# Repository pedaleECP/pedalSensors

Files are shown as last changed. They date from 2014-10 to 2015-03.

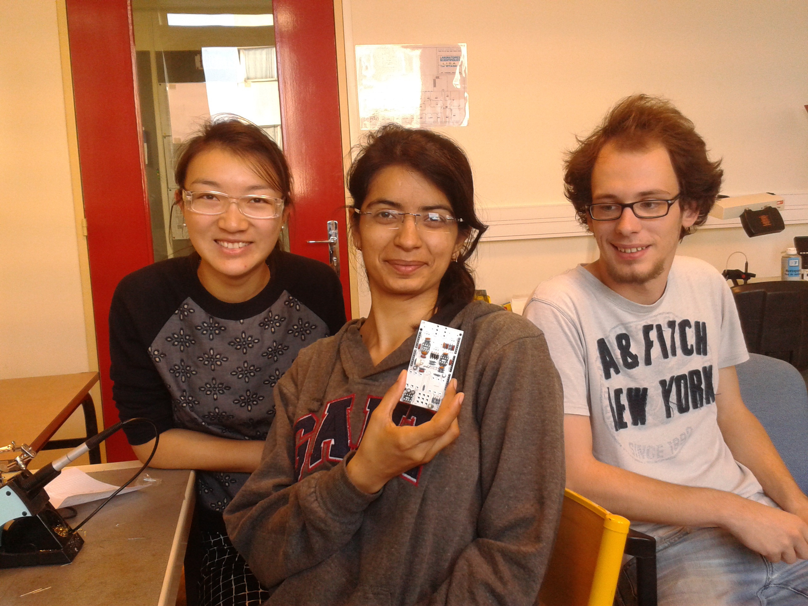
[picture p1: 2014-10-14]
Documentation/Photos/2014-09-30 Scéance 2 - Fabrication du pedalSHIELD/IMG_20140930_173658.jpg

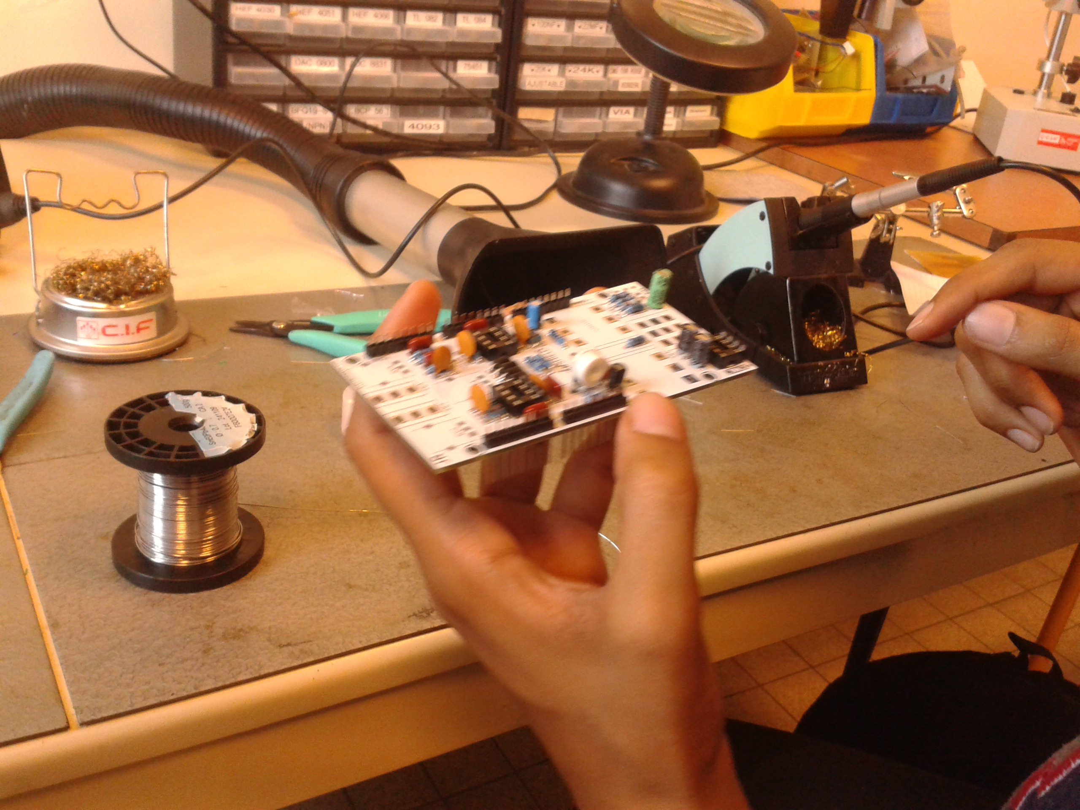
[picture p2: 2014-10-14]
Documentation/Photos/2014-09-30 Scéance 2 - Fabrication du pedalSHIELD/IMG_20140930_173621.jpg

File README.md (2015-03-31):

pedalSHIELD
===========

Check from Esteban
Deuxieme chek from Esteban

pedalSHIELD is an Arduino Open Source guitar pedal made for guitarists, hackers and programmers. Users can program their own effects in C/C++ or download ready effects from the online library.

It is designed to be a platform to learn about digital signal processing, effects, synthesizers and experiment without deep knowledge in electronics or programming

All info in www.electrosmash.com/pedalshield

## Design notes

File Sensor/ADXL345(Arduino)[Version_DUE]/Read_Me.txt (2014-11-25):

The code is provided under the MIT license please use, edit, change, and share. 

The Adxl345 library has been modified for use with this example
The Adxl345 library however is provided under the GPL V2 license.

Before loading the ADXLl345_example code, or even opening the arduino software, place the Adxl345 folder in your arduino library.

////ARDUINO LIBRARY LOCATION////
On your Mac:: In (home directory)/Documents/Arduino/libraries
On your PC:: My Documents -> Arduino -> libraries
On your Linux box: (home directory)/sketchbook/libraries

##Changes from pedalSensors team:
We adapted the library to be used with ArduinoDUE

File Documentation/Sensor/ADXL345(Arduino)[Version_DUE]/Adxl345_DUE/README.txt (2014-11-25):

Adaptadted version of the ADXL345 library for Arduino DUE from pesalSensors team

based in "masc" post in http://forum.bildr.org/viewtopic.php?f=29&t=349&start=75

Arduino Due should be connected as follows:

ADXL345					Arduino DUE
3.3V	-----------------------------	3.3V
GND	-----------------------------	GND
SCL	-----------------------------	SCL 21
SDA	-----------------------------	SDA 20

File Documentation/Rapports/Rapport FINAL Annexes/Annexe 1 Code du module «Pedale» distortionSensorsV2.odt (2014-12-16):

Annexe 1

Code du module «Pedale»

distortionSensorsV2.ino

/*********************************************************************

*********** distortion Effect for the MovingTones pedal **********

*********** made by the MovingTones team **********

*********** website :) **********

* Licensed under a Creative Commons Attribution 3.0 Unported License *

**********************************************************************

*********** effect adapted from the distortion effect by ***********

*********** www.electrosmash.com/pedalshield **********

*********** Based on rcarduino.blogspot.com previous work **********

**********************************************************************/

/* To make this code compile you will need the following libraries:

* Adafruit_ST7735

* Adafruit_GFX

* SPI.h

* EEPROM.h */

// Libraries

#include "EEPROM.h" //

#include <Adafruit_GFX.h> // Core graphics library

#include <Adafruit_ST7735.h> // Hardware-specific library

#include <SPI.h> // Used during debugging to show messages on the Serial print

// Variables from the original effects' code

int in_ADC0, in_ADC1; // variables for 2 ADCs values (ADC0, ADC1)

int POT0, POT1, POT2, out_DAC0, out_DAC1; // variables for 3 pots (ADC8, ADC9, ADC10)

const int LED = 3; // LED in pin 3

const int FOOTSWITCH = 7; // Footswitch in pin 7

const int TOGGLE = 2; // Toggle in pin 2

int upper_threshold, lower_threshold; // Variable for the distortion effect

const int SAVE_BUTTON = 1; // pins of the arduino

const int TFT_CS = 10;

const int TFT_RST = 8;

const int TFT_DC = 9;

Adafruit_ST7735 tft = Adafruit_ST7735(TFT_CS, TFT_DC, TFT_RST); // instantiate the screen

// New variables

const int STANDBY1_MODE = 0; // effects will only be applied when the pedal's footswitch is on HIGH

const int BUTTON_MODE = 1; // sequence of pressing produces: low-high-low-high or high-low-high-low

const int STANDBY2_MODE = 2; // if initially footswitch is HIGH, we will go to BUTTON_MODE

const int SENSOR_MODE = 3; // if intiially footswitch is LOW, we will go to STANDBY1_MODE

const int DEBOUNCE_DELAY = 50; // delay to be applied to debounce

const int MIN = 0; // range of the parameters p0, p1, p2 for the effects' code

const int MAX = 4096;

const int MIN_SCREEN = 0; // length of the bar graph to be displayed on the screen

const int MAX_SCREEN = 115;

const int MAX_POT = 4096; // readings from the bottons will be scaled to this range

const int MIN_POT = 0;

const int LIMIT_POT = 4096;

const int MAX_SENSORS = 180; // sensors send angles in this range throught the XBees

const int MIN_SENSORS = 0;

int footswitch_detect; // variables to fascilitate the toggle

int footswitch_detect_last;

int footswitch_detect_previous;

int save_button_detect; // currently not used

int save_button_press_time;

boolean save_button_pressed;

int footswitch_mode = STANDBY1_MODE; // instantiate footswitch_mode to STANDBY1_MODE

int last_debounce_time = 0; // variables to fascilitate debouncing

int last_update_time = 0;

int p0 = 0, p1 = 0, p2 = 0; // parameters to be used by the code to apply effects accordingly

int p0_old, p1_old, p2_old;

int MEMORYPOTMOD0 = 0, MEMORYPOTMOD1 = 0, MEMORYPOTMOD2 = 0;

// Variables needed for the comunication with the ArduinoNano who is sending information in Serial Port

byte incomingByte; //Bytes that are going to be used to add them and to see if there is any header between they two.

byte lastByte; // This will be just the byte before incomingByte

// Variables to assemble 16-bits ints from bytes received form the Arduino Nano through the XBees

// !!! Note that int on an Arduino DUE is 32-bit but in many other smaller Arduinos it is 16-bit

// Thus to avoid negative-wrapping-around-to-positive, use int16_t for all int variables in this program

int16_t currentInt;

int16_t int1;

byte byteArray[3];

int16_t angles[3]; // the three angles read by the sensor as received from XBees

int16_t mask;

void setup()

{

//Configuration from the original effect from pedalShield

//ADC Configuration

ADC->ADC_MR |= 0x80; // DAC in free running mode.

ADC->ADC_CR = 2; // Starts ADC conversion.

ADC->ADC_CHER = 0xFFFF; // Enable all ADC channels

//DAC Configuration

analogWrite(DAC0, 0); // Enables DAC0

analogWrite(DAC1, 0); // Enables DAC1

// We are going to read from the FootSwitch to make our 3 modes.

pinMode(FOOTSWITCH, INPUT); // Enables to read from the footswitch

// pinMode(SAVE_BUTTON, INPUT);

pinMode(LED, OUTPUT);

// record the state of the footswitch when turned on

/*HERE WE SHOULD DETECT IF HI IS ALEREADY IN BYPASSMODE OR NOT. AND THEN START FROM HIS ORIGINAL STATE

*******************************************************************************************************/

footswitch_mode = digitalRead(FOOTSWITCH);

footswitch_detect_last = digitalRead(FOOTSWITCH);

footswitch_detect_previous = footswitch_detect_last;

//Screen (add description and comments)

tft.initR(INITR_BLACKTAB);

tft.fillScreen(ST7735_BLACK);

// Here we set the screen parameters: orientation, text size, color and text display

tft.setRotation(-1);

tft.setTextSize(2);

tft.fillScreen(ST7735_WHITE);

tft.setTextColor(ST7735_RED);

tft.println("*Distortion*");

tft.println("");

tft.println(" P1");

tft.println("");

tft.println(" P2");

tft.println("");

tft.println(" P3");

p0_old = p0;

p1_old = p1;

p2_old = p2;

// Initialize the Serial ports for message transmissions

Serial.begin(57600); //Initialize the port for comunication with the PC to send messages useful for coding (Serial)

Serial1.begin(57600); //Initialize the port for comunication with the XBee (Serial1)

// From XBee

lastByte = (byte)0; // We inicialize the lastBythe with 0 so it can make its first comparison.

}

void loop()

{

readFootSwitch(); //We read the FootWwitch State and we see if it's pressed.

updateScreen(); //We upload the screen information

// readSaveButton();

// From the original effect code

// Read the ADCs

while ((ADC->ADC_ISR & 0x1CC0) != 0x1CC0); // wait for ADC 0, 1, 8, 9, 10 conversion complete.

in_ADC0 = ADC->ADC_CDR[7]; // read data from ADC0

in_ADC1 = ADC->ADC_CDR[6]; // read data from ADC1

// POT0=ADC->ADC_CDR[10]; // read data from ADC8

// POT1=ADC->ADC_CDR[11]; // read data from ADC9

// POT2=ADC->ADC_CDR[12]; // read data from ADC10

// Changing the parameters values depending of the mode

switch (footswitch_mode) {

case STANDBY1_MODE:

case STANDBY2_MODE:

Serial.print("Standby Mode ");

break;

case BUTTON_MODE:

Serial.print("Button Mode: ");

readPotentiometer();

break;

case SENSOR_MODE:

Serial.print("Sensor Mode: ");

readSensor();

break;

default:

Serial.print("Invalid state ");

}

// We display the parameters values on the computer screen

Serial.print(p0);

Serial.print("|");

Serial.print(p1);

Serial.print("|");

Serial.print(p2);

Serial.print("|");

Serial.println("");

// Code for the effect 'distortion' - distortion does not use parameter p1

// Code from the original effect: This is the effect, taking the parameters p0, p1 and p2

upper_threshold = map(p0, 0, 4095, 4095, 2047);

lower_threshold = map(p0, 0, 4095, 0000, 2047);

if (in_ADC0 >= upper_threshold) in_ADC0 = upper_threshold;

else if (in_ADC0 < lower_threshold) in_ADC0 = lower_threshold;

if (in_ADC1 >= upper_threshold) in_ADC1 = upper_threshold;

else if (in_ADC1 < lower_threshold) in_ADC1 = lower_threshold;

//adjust the volume with POT2

out_DAC0 = map(in_ADC0, 0, 4095, 1, p2);

out_DAC1 = map(in_ADC1, 0, 4095, 1, p2);

//Write the DACs

dacc_set_channel_selection(DACC_INTERFACE, 0); //select DAC channel 0

dacc_write_conversion_data(DACC_INTERFACE, out_DAC0); //write on DAC

dacc_set_channel_selection(DACC_INTERFACE, 1); //select DAC channel 1

dacc_write_conversion_data(DACC_INTERFACE, out_DAC1); //write on DAC

}

// reading the FOOTSWITCH on the pedalShield and implement a debouncing mechanism

void readFootSwitch() {

footswitch_detect = digitalRead(FOOTSWITCH);

if (footswitch_detect != footswitch_detect_last) {

last_debounce_time = millis();

}

if (footswitch_detect != footswitch_detect_previous && millis() - last_debounce_time > DEBOUNCE_DELAY) {

footswitch_mode = (footswitch_mode + 1) % 4;

footswitch_detect_previous = footswitch_detect;

}

footswitch_detect_last = footswitch_detect; // we detect changes in the FOOTSWITCH by comparing these two variables

}

void readSaveButton() {

save_button_detect = digitalRead(SAVE_BUTTON);

if (save_button_detect == HIGH) {

last_debounce_time = millis();

if (save_button_pressed = true) {

if (millis() - save_button_press_time > 3000) {

EEPROM.write(0, p0);

EEPROM.write(1, p1);

EEPROM.write(2, p2);

} else {

p0 = EEPROM.read(0);

p1 = EEPROM.read(1);

p2 = EEPROM.read(2);

}

save_button_pressed = false;

}

}

if (save_button_detect == LOW && millis() - last_debounce_time > DEBOUNCE_DELAY && save_button_pressed == false) {

save_button_press_time = millis();

save_button_pressed = true;

}

}

void readPotentiometer() {

int POTMOD0 = ADC->ADC_CDR[2]; //reading first potentiometer

POT0 = updatePot(POT0, MEMORYPOTMOD0, POTMOD0); //update first parameter using current reading of potentiometer

p0 = POT0; //update globally

MEMORYPOTMOD0 = POTMOD0; //now the potentiometer reading becomes the 'previous' reading

//Serial.println(p0);

int POTMOD1 = ADC->ADC_CDR[1]; //read from pot1 //reading second potentiometer

POT1 = updatePot(POT1, MEMORYPOTMOD1, POTMOD1); //update second parameter using current reading of potentiometer

p1 = POT1; //update globally

MEMORYPOTMOD1 = POTMOD1; //now the potentiometer reading becomes the 'previous' reading

int POTMOD2 = ADC->ADC_CDR[0]; //read from pot2 //reading third potentiometer

POT2 = updatePot(POT2, MEMORYPOTMOD2, POTMOD2); //update third parameter using current reading of potentiometer

p2 = POT2; //update globally

MEMORYPOTMOD2 = POTMOD2; //now the potentiometer reading becomes the 'previous' reading

}

int updatePot(int POT, int MEMORYPOTMOD, int POTMOD) { //update the given parameter

int VALUE = 0; //Value to be added to previous values of parameters

if ((POTMOD - MEMORYPOTMOD) < -0.9 * MAX_POT) { // case of more than one complete turn in the positive direction

VALUE = MAX_POT + POTMOD - MEMORYPOTMOD;

if ((POT + VALUE) > LIMIT_POT) {

POT = LIMIT_POT;

}

else {

POT = POT + VALUE ;

}

}

else if ((POTMOD - MEMORYPOTMOD) > 0.9 * MAX_POT) { // case of more than one complete turn in the negative direction

VALUE = - (MAX_POT) + POTMOD - MEMORYPOTMOD;

if ((POT + VALUE) < MIN_POT) {

POT = MIN_POT;

}

else {

POT = POT + VALUE ;

}

}

else if ((POTMOD - MEMORYPOTMOD) > 0) { //case of less than one complete turn in the positive direction

VALUE = POTMOD - MEMORYPOTMOD;

if ((POT + VALUE) > LIMIT_POT) {

POT = LIMIT_POT;

}

else {

POT = POT + VALUE ;

}

}

else if ((POTMOD - MEMORYPOTMOD) < 0) { //case of less than one complete turn in the negative direction

VALUE = POTMOD - MEMORYPOTMOD;//+POTSENSOR

if ((POT + VALUE) < MIN_POT) {

POT = MIN_POT;

}

else {

POT = POT + VALUE ;

}

}

return POT;

}

// Read the 3 angles transmitted by the XBees if there is message available

// The 3 angles (6 bytes) are always sent together following an int header == -21846

void readSensor() {

if (Serial1.available()) {

boolean header = false; // before a valid header is detected, header is set to false

lastByte = Serial1.read(); // read one byte

while (Serial1.available() && !header) {

incomingByte = Serial1.read(); // read another byte

int1 = assembleInt(lastByte, incomingByte); // each int is 16-bit, so we assemble the incoming int by applying bit-wise operations on the two bytes

// Serial.println("waiting"); // uncomment this line to see how long it takes to clear the buffer

if (int1 == -21846) {

header = true; // a correct header is detected

}

else {

lastByte = incomingByte; // if there is not any header we take our second byte as our first byte, to then make a comparison with the following

}

}

// if the header is detected, the next 6 bytes are the 3 values of the angles (each int is 16-bit)

readAngles();

}

}

// assemble an int from the two bytes just read into byteArray

int16_t assembleInt(byte byte1, byte byte2) {

currentInt = (int16_t)byte1 << 8;

mask = 0xFF;

mask = mask & (int16_t)byte2; // mask the first 8 bit to zero, in case the byte is sign-extended

currentInt = currentInt | mask;

// the byte1*256 + byte2 before is wrong because byte2 had been sign-extended - have to mask the first 8 bits

//mask = 0xFF;

//currentInt = byte1*256 + (byte2 & mask);

return currentInt;

}

// Read the angles from the next 6 bytes (2 bytes for each 16-bit int angle)

void readAngles() {

// Expect 3 angles

for (int i = 0; i < 3; i++) {

/* We know that we should have a message in the buffer, (because we have reconized an header)

but, it can happen that the pedal tries to read the angles form the Serial before the sensor

manage to send him the angles (it can also be because of the data transmission speed v/s

the pedal's processor speed)

so here we wait for the next message if it's necessary

TODO: Use a timout!!*/

while (!Serial1.available()) {

Serial.println("----Im waiting111111-");

}

byteArray[0] = Serial1.read(); // We read the fist byte

while (!Serial1.available()) { // We wait again in case it is necesary TODO: Use a timout!!

Serial.println("----Im waiting222222-");

}

byteArray[1] = Serial1.read(); // We read the second byte

angles[i] = assembleInt(byteArray[0], byteArray[1]); // We construct the angle using both bytes

}

/*Sometimes, (and I don't know yet why.. and this is a ToDo:try to prevent this from another way)

there are some messages that are eathier read badly or sended badly.. so we delete any message with an

incorrect angle*/

if (angles[0] >= 0 && angles[0] <= MAX_SENSORS && angles[1] >= 0 && angles[1] <= MAX_SENSORS && angles[2] >= 0 && angles[2] <= MAX_SENSORS) {

// Writing the angles into the global variables

p0 = angles[0] * 4096 / MAX_SENSORS; //Here we scale the angle into our effect scale. here is until 4096

p1 = angles[1] * 4096 / MAX_SENSORS;

p2 = angles[2] * 4096 / MAX_SENSORS;

}

}

void updateScreen() {

// only update the screen every 0.1 seconds

if (millis() - last_update_time > 100) {

last_update_time = millis();

// if the new parameter is bigger than the old one, add a blue bar

// else add a white bar. this scheme is applied for every parameter.

if (p0_old < p0) {

tft.fillRoundRect(MIN_SCREEN, 32, map(p0, MIN, MAX, MIN_SCREEN, MAX_SCREEN), 16, 0, ST7735_BLUE);

}

if (p0_old > p0) {

tft.fillRoundRect(map(p0, MIN, MAX, MIN_SCREEN, MAX_SCREEN), 32, map(p0, MIN, MAX, MAX_SCREEN, MIN_SCREEN), 16, 0, ST7735_WHITE);

}

p0_old = p0;

if (p1_old < p1) {

tft.fillRoundRect(MIN_SCREEN, 64, map(p1, MIN, MAX, MIN_SCREEN, MAX_SCREEN), 16, 0, ST7735_BLUE);

}

if (p1_old > p1) {

tft.fillRoundRect(map(p1, MIN, MAX, MIN_SCREEN, MAX_SCREEN), 64, map(p1, MIN, MAX, MAX_SCREEN, MIN_SCREEN), 16, 0, ST7735_WHITE);

}

p1_old = p1;

if (p2_old < p2) {

tft.fillRoundRect(MIN_SCREEN, 96, map(p2, MIN, MAX, MIN_SCREEN, MAX_SCREEN), 16, 0, ST7735_BLUE);

}

if (p2_old > p2) {

tft.fillRoundRect(map(p2, MIN, MAX, MIN_SCREEN, MAX_SCREEN), 96, map(p2, MIN, MAX, MAX_SCREEN, MIN_SCREEN), 16, 0, ST7735_WHITE);

}

p2_old = p2;

}

}

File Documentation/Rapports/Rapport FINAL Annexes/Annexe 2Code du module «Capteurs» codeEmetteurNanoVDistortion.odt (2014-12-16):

Annexe 2

Code du module «Capteurs»

codeEmetteurNanoVDistortion.ino

/*********************************************************************

*********** code pour l'emeteur des angles Yaw,Roll,Pitcc **********

*********** made by the MovingTones team **********

*********** website :) **********

* Licensed under a Creative Commons Attribution 3.0 Unported License *

**********************************************************************/

/* Les angles ici envoyes seront les angles Yaw,Roll,Pich

plus d'info : http://en.wikipedia.org/wiki/Aircraft_principal_axes

C'est necesaire d'avoir les libreries suivantes:

* FreeSixIMU

* FIMU_ADXL345

* FIMU_ITG3200

Vous pouvez les trouver sur:

http://bildr.org/2012/03/stable-orientation-digital-imu-6dof-arduino/*/

//Importation des bilbiotheques

#include <FreeSixIMU.h>

#include <FIMU_ADXL345.h>

#include <FIMU_ITG3200.h>

#include <Wire.h>

float angles[3]; //Ici on va stocker les angles.

//float accel[3]; //Si jamais on a besoin des accelerations

FreeSixIMU sixDOF = FreeSixIMU(); // Set the FreeSixIMU object

void setup() {

Wire.begin();

Serial.begin(57600); //C'est necesaire pour envoyer les messages via XBee

delay(5);

sixDOF.init(); //begin the IMU

delay(5);

}

void loop() {

//sixDOF.getEuler(angles); //Si jamais on a besoin des angles d'euler

//sixDOF.getValues(accel); //Si jamais on a besoin des accelerations

sixDOF.getYawPitchRoll(angles); //On a choisi d'utiliser ces angles car sont plus intuitives dans le mouvement

angles[0]=abs(angles[0]); // Comme l'angle va de -180 a +180 on le change pour etre de 0 --- 150--180--150--0 etc...

//Mais en fait l'angle Yaw va de -180 jusqu'a +180, donc on va se restrindre a la plage 0 180.

//TODO: Take advantaje of this large angle.

// if (angles[0]>180){angles[0]=180;}

// if (angles[0]<0){angles[0]=0;}

angles[1]=angles[1]+90; // Comme l'angle va de -90 a +90 on le change pour etre de 0 a 180

angles[2]=angles[2]+90; // Comme l'angle va de -90 a +90 on le change pour etre de 0 a 180

//Si on a besoin de voir les angles qu'on envoie, on peut les afficher sur l'ecran de l'ordinateur

//Mais il y aura des problemes dans les messages recoit par la pedale: L'ordinateur et le Xbee utilisent le meme port serial de l'arduino nano (unique)

/* Serial.print(angles[0]);

Serial.print(" | ");

Serial.print(angles[1]);

Serial.print(" | ");

Serial.print(angles[2]);

Serial.println();*/

envoyeAngles(angles[1],angles[0],angles[2]); //On envoie finnalement les angles a la pedale a travers du port Serial.

}

void envoyeAngles(float psi, float theta, float phi){

int16_t psiInt = (int16_t)(psi); //On va envoyer des integers, car c'est plus facile et on n'a pas besoin d'assez de precition

int16_t thetaInt = (int16_t)(theta); //On va envoyer des integers, car c'est plus facile et on n'a pas besoin d'assez de precition

int16_t phiInt = (int16_t)(phi); //On va envoyer des integers, car c'est plus facile et on n'a pas besoin d'assez de precition

//Ici, pour chaque angle en variable type integer, on va lui diviser en deux octets en on va lui envoyer un par un

//Toud d'abord on envoye le "header" qui est 0xAAAA= -21846

Serial.write(0xAAAA/ 256); //on envoye la premiere partie

Serial.write(0xAAAA% 256); //on envoye la deuxieme partie

Serial.write(psiInt / 256); //on envoye la premiere partie

Serial.write(psiInt% 256); //on envoye la deuxieme partie

Serial.write(thetaInt / 256); //on envoye la premiere partie

Serial.write(thetaInt% 256);

Serial.write(phiInt/ 256); //on envoye la premiere partie

Serial.write(phiInt% 256); //on envoye la deuxieme partie

}

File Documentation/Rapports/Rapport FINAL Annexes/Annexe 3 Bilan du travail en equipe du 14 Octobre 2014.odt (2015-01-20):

Annexe 3 - Bilan du travail en équipe du 14 Octobre 2014

Notre stratégie a été de se répartir en petits groupes(deux ou trois) en fonction des tâches à venir. Cela permet une organisation libre et permet de ne pas se restreindre à un type de tâche spécifique (hardware/software, par exemple). Nous avons trouvé cette stratégie efficace: programmation, assemblage des composants, soudure et recherche sur Internet sont plus efficaces en petits groupes, qui permettent d’avoir assez de place pour s’exprimer, sans avoir à faire trop de coordination ce qui résulte en un travail à la fois rapide et efficace.

Cependant, il est important d’avoir des réunions ensemble, nous avons donc des réunions tous ensemble chaque mardi, comme ça nous pouvons rester informés des progrès de notre projet entier, et nous pouvons aussi discuter, attribuer les tâches à venir et demander de l’aide si un petit groupe ne peut pas résoudre un problème dans le planning. En même temps, nous voulons maintenir une atmosphère détendue et pas stressante.

Nous sommes très heureux d’avoir un groupe extraordinairement divers: chacun de nous a une nationalité différente (Chine, Inde, Mexique, Allemagne, France et Chili). Le plupart d’entre nous sont étudiants en échange ce qui permet de partager les techniques et des plate-formes que nous utilisions dans nos universités (cf Asana, GitHub, dynamiques de travail en équipe). Après ce semestre, nous les remporterons chez nous et les utiliserons dans nos futurs projets. Il y a donc un enrichissement personnel et culturel.

En outre, l’idée d’un projet Open Source nous enthousiasme, ainsi que le fait de contribuer à la communauté en ligne et d’exposer l’idée aux étudiants à l’Ecole Centrale Paris.

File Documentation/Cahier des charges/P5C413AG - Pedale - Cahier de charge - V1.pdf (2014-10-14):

P5C413AG - 2014 - Cahier des charges

Cahier des charges.

Nom du Projet: Pédale d'effet numérique pour guitare électrique

Code du Projet: P5C413AG

Encadrant du Projet: Jean-Pierre FANTON

Membres du groupe:

- AHUJA, Sanju
- IGLESIAS MANRÍQUEZ, Esteban Felipe.
- MARTINEZ ARROYO, Andrea Lorena.
- PARENT, Nicolas.
- WIEDEMANN, Andreas.
- YANG, Siyu.

Objectif du projet:

Le but du projet est la réalisation d'une pédale pour modifier le son émis par une guitare électrique en utilisant des effets digitaux, dont les paramètres peuvent être changés suivant les mouvements du corps du musicien. C'est une exploration des nouvelles manières de créer de la musique et une utilisation des technologies digitales pour l'art.

Le projet sera développé sur les principes des projets Open Source et Open Hardware.

Description du Produit: La pédale et les senseurs.

Pédale d'effet numérique pour guitare électrique en utilisant Arduino. Les préférences des effets seront réglés par des senseurs de mouvement qui seront attachés au corps du musicien.

Fonctionnalités:

F1. La pédale doit avoir trois modes:
Un mode sans effets, un mode avec les effets actifs contrôlés seulement par les boutons; et un troisième mode avec les effets contrôlés par les mouvements du musicien.

F2. Visualisation:
La pédale doit indiquer le niveau des paramètres de l'effet et le nom de l'effet.

F3. Boutons et 3 paramètres:
La pédale doit posséder des réglages manuels pour les 3 paramètres de l'effet.

F4. Sauvegarde:
La pédale doit avoir la possibilité de sauvegarder la configuration des paramètres pour les récupérer.

P5C413AG - 2014 - Cahier des charges

F5. Détection des mouvement:
La pédale doit détecter les mouvements du corps du musicien grâce à des capteurs sur son corps. Ces capteurs doivent posséder 3 degrés de liberté pour interagir avec les 3 paramètres de l'effet.

F6. Communication sans fil:
La pédale et les capteurs doivent communiquer sans fil.

F7. Sensibilité contrôlée:
La sensibilité des capteurs doit pouvoir être modifiée par l'utilisateur.

F8. Effets programmables sur ordinateur.
Les différents effets doivent pouvoir être programmées par l'utilisateur sur un ordinateur.

F9. Open source
Le développement du projet doit se faire en Open Source et le projet doit être partagé.

Date de Présentation: Fin du Semestre 7.

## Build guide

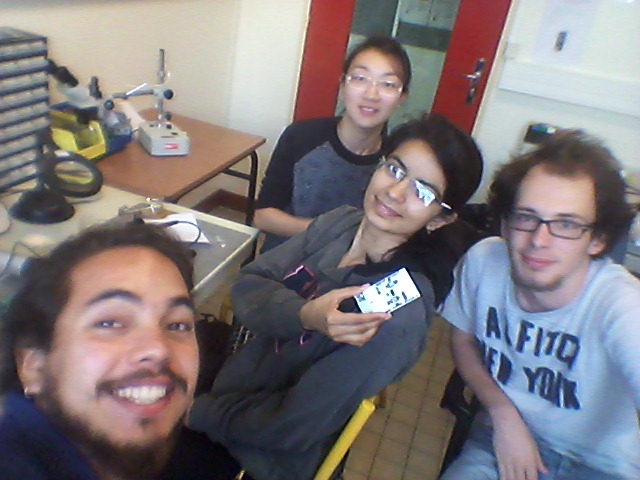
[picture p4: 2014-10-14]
Documentation/Photos/2014-09-30 Scéance 2 - Fabrication du pedalSHIELD/IMG_20140930_173712.jpg

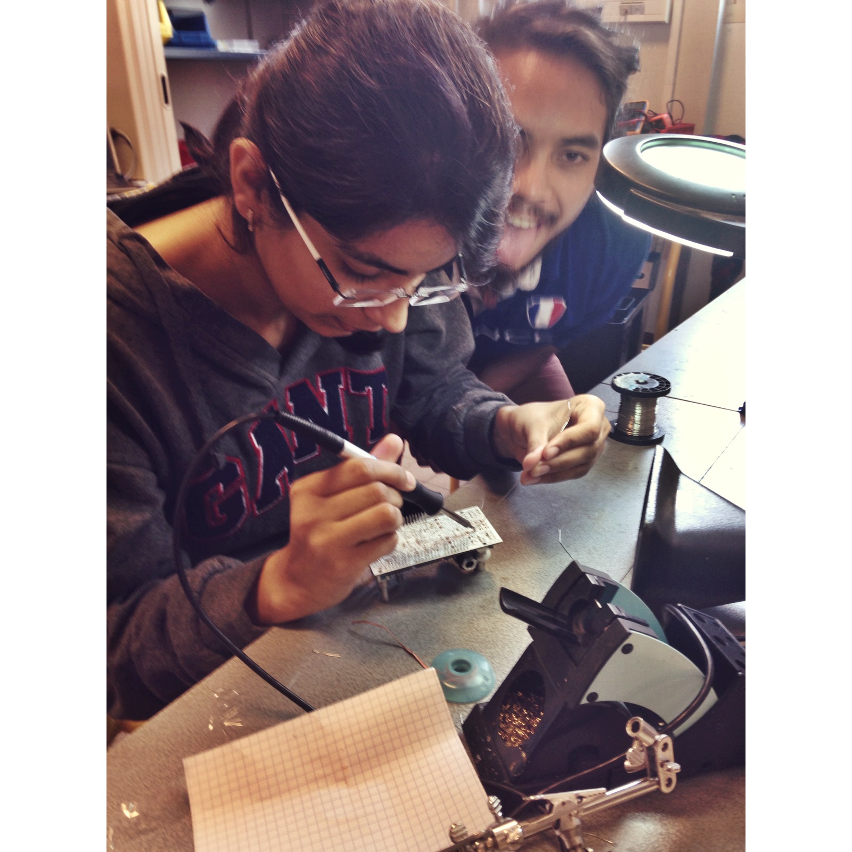
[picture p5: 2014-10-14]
Documentation/Photos/2014-09-30 Scéance 2 - Fabrication du pedalSHIELD/IMG_3899.JPG

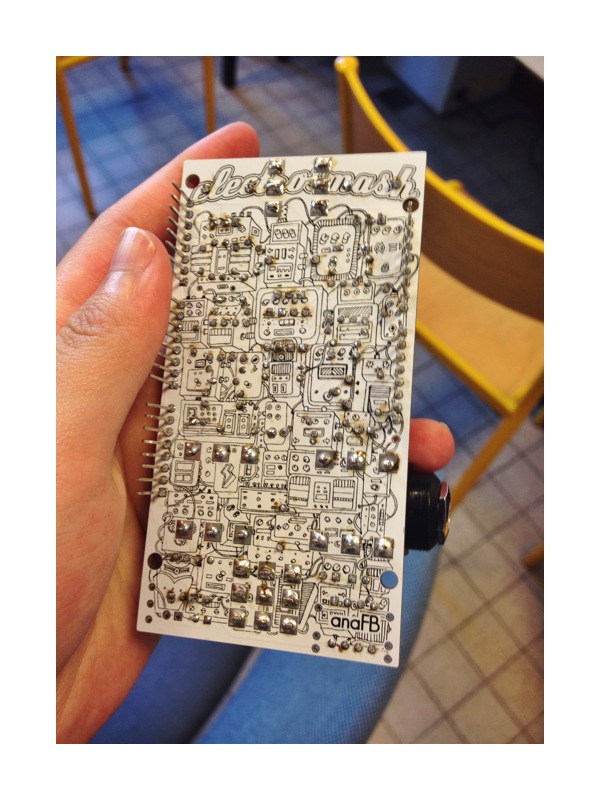
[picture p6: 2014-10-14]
Documentation/Photos/2014-09-30 Scéance 2 - Fabrication du pedalSHIELD/IMG_3900.JPG

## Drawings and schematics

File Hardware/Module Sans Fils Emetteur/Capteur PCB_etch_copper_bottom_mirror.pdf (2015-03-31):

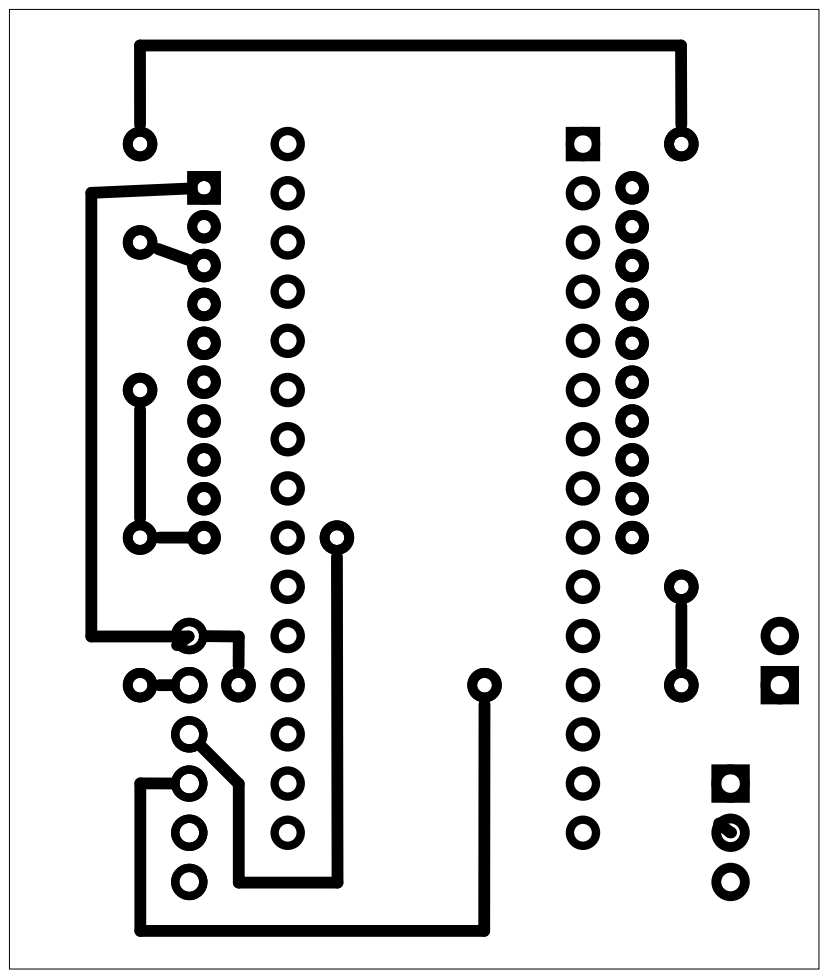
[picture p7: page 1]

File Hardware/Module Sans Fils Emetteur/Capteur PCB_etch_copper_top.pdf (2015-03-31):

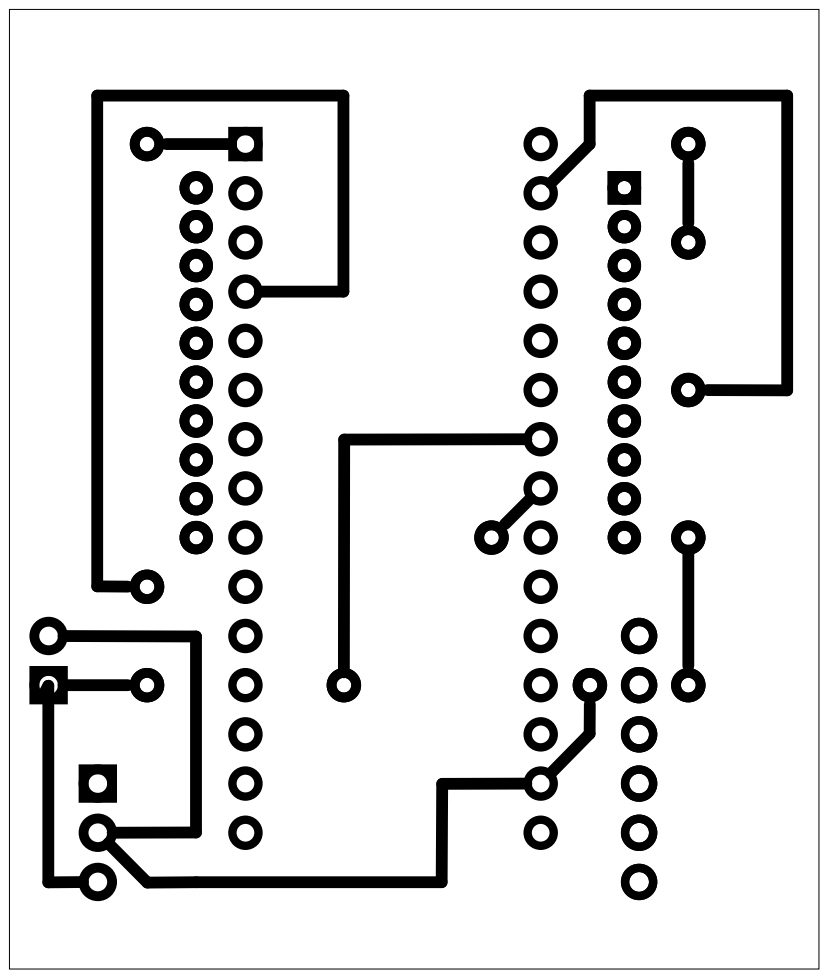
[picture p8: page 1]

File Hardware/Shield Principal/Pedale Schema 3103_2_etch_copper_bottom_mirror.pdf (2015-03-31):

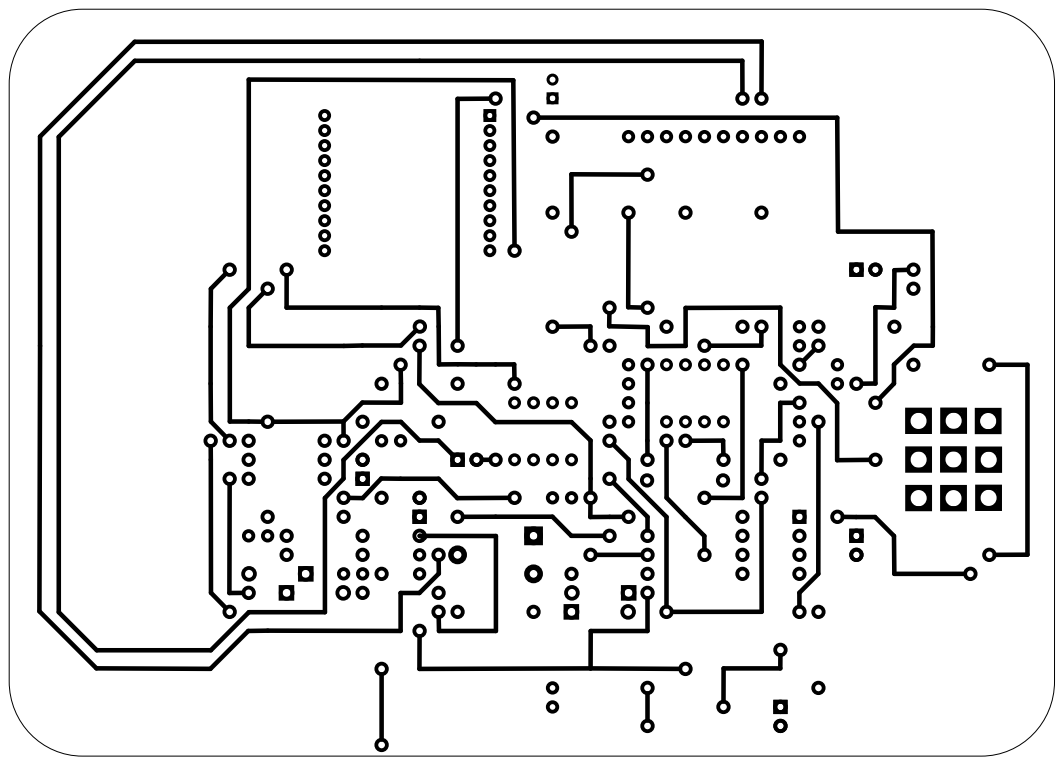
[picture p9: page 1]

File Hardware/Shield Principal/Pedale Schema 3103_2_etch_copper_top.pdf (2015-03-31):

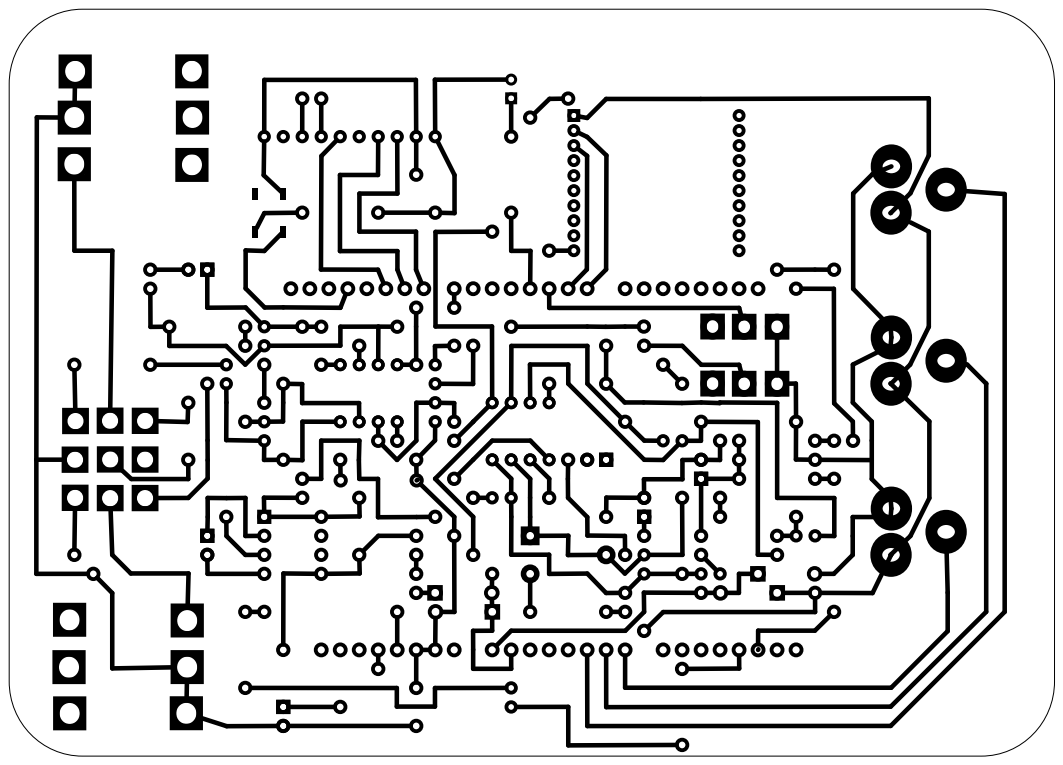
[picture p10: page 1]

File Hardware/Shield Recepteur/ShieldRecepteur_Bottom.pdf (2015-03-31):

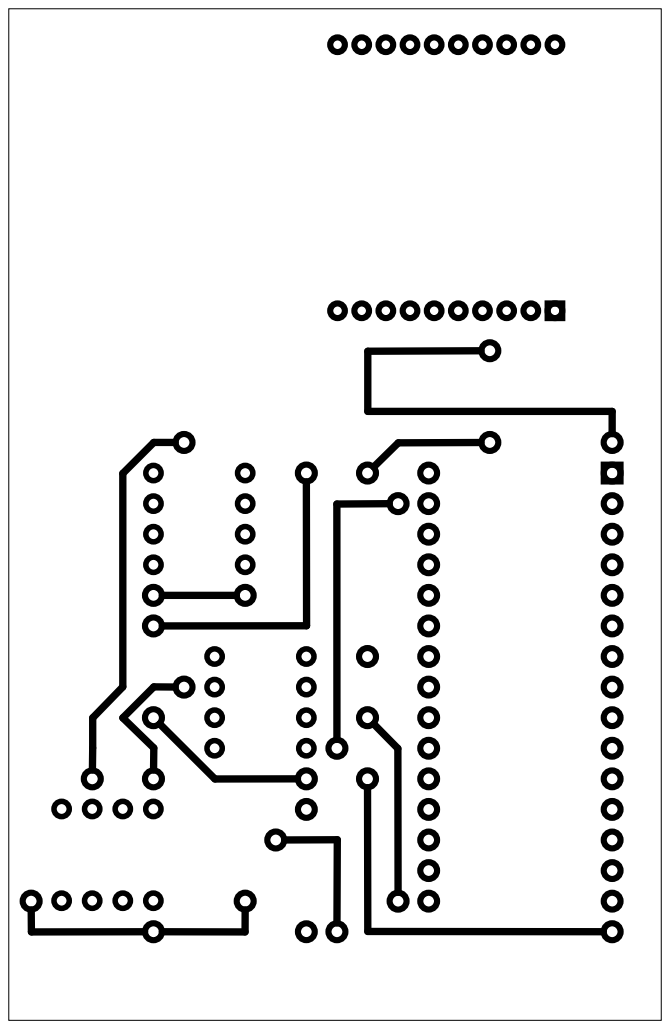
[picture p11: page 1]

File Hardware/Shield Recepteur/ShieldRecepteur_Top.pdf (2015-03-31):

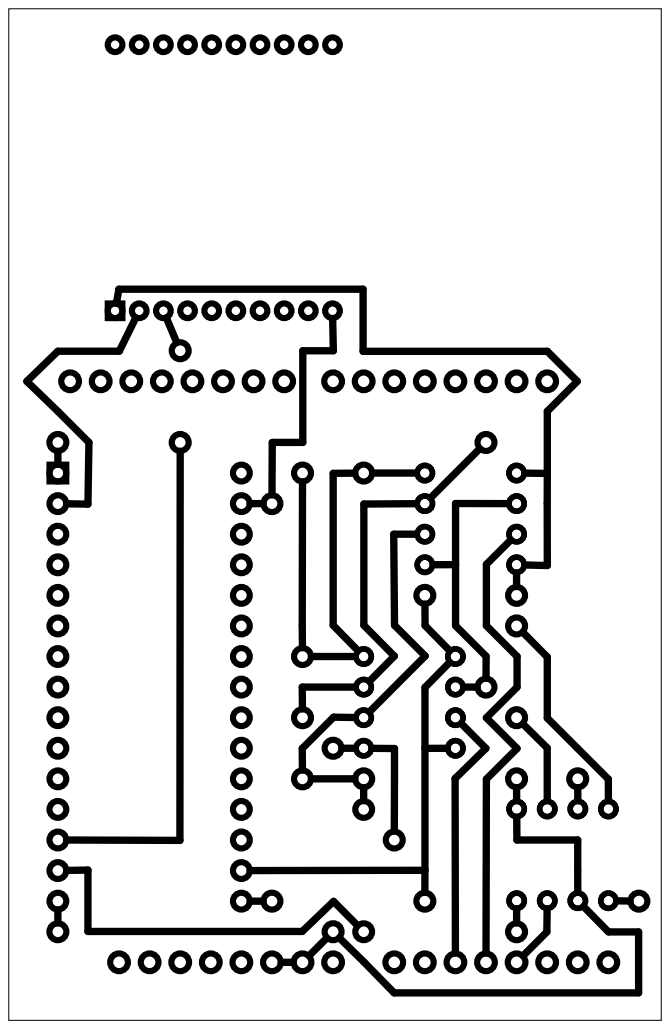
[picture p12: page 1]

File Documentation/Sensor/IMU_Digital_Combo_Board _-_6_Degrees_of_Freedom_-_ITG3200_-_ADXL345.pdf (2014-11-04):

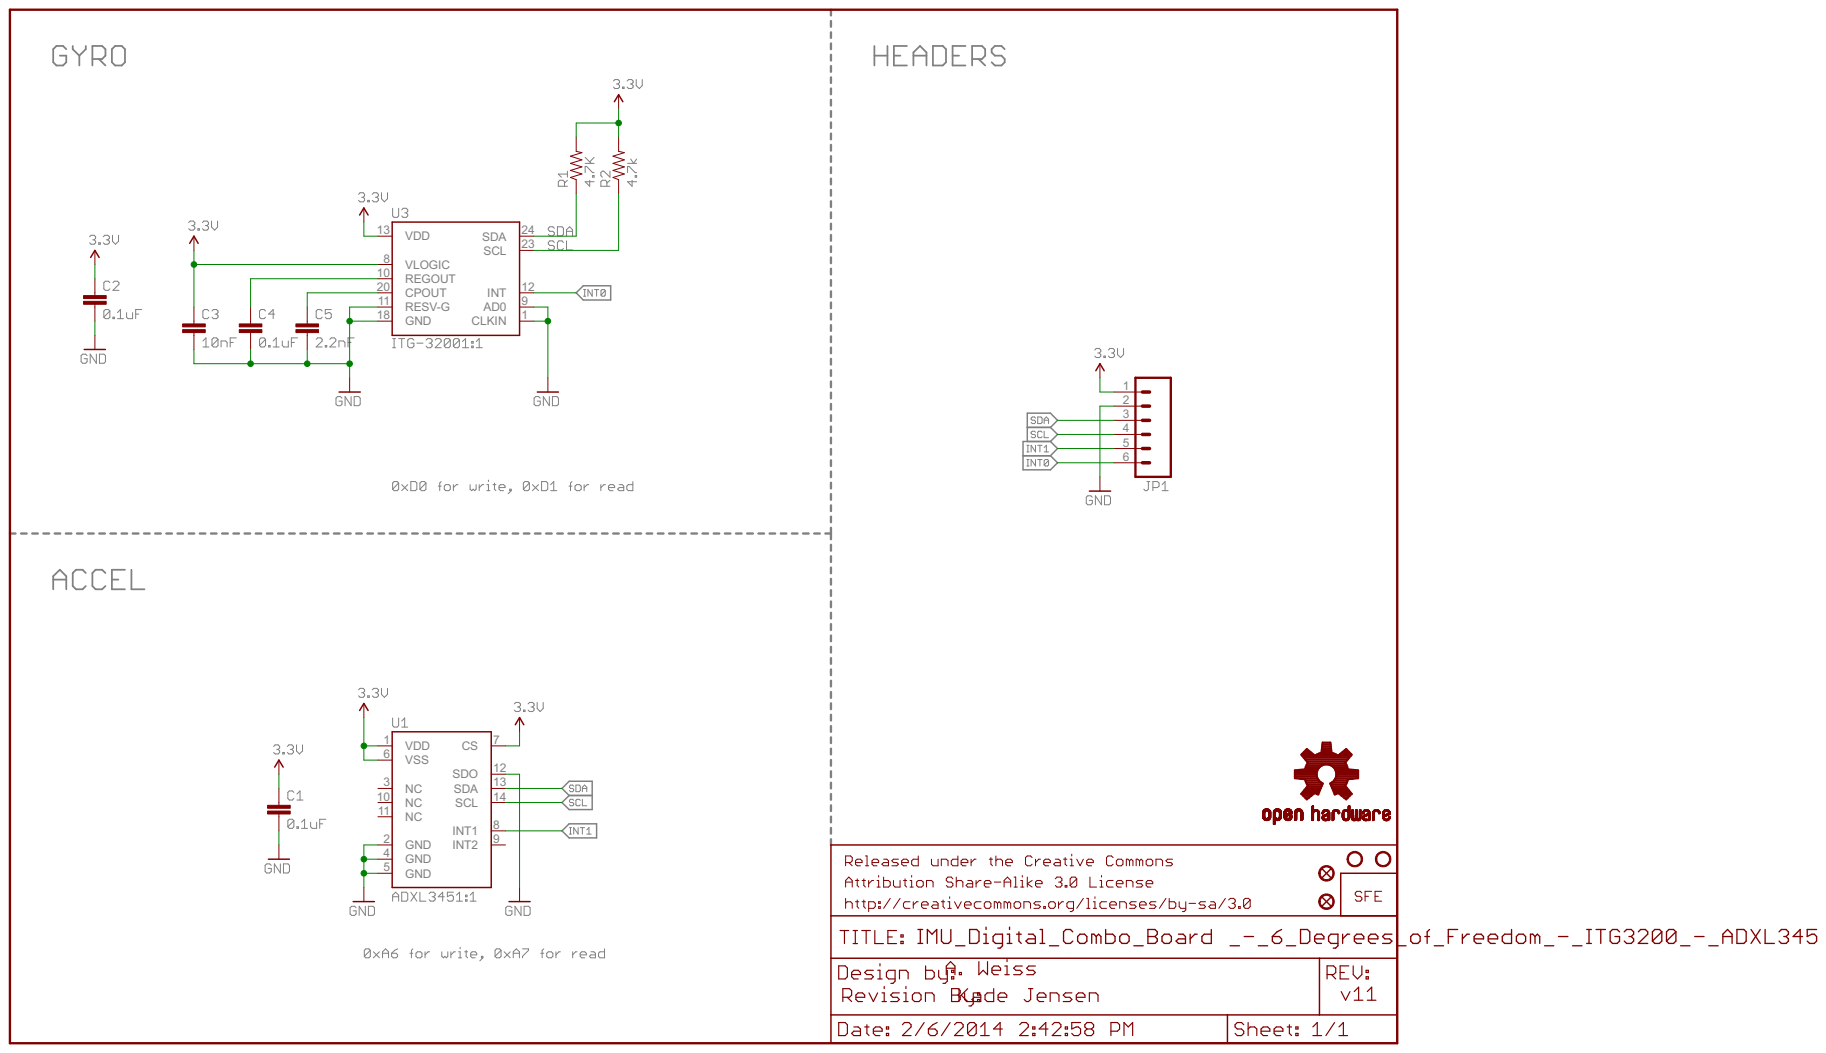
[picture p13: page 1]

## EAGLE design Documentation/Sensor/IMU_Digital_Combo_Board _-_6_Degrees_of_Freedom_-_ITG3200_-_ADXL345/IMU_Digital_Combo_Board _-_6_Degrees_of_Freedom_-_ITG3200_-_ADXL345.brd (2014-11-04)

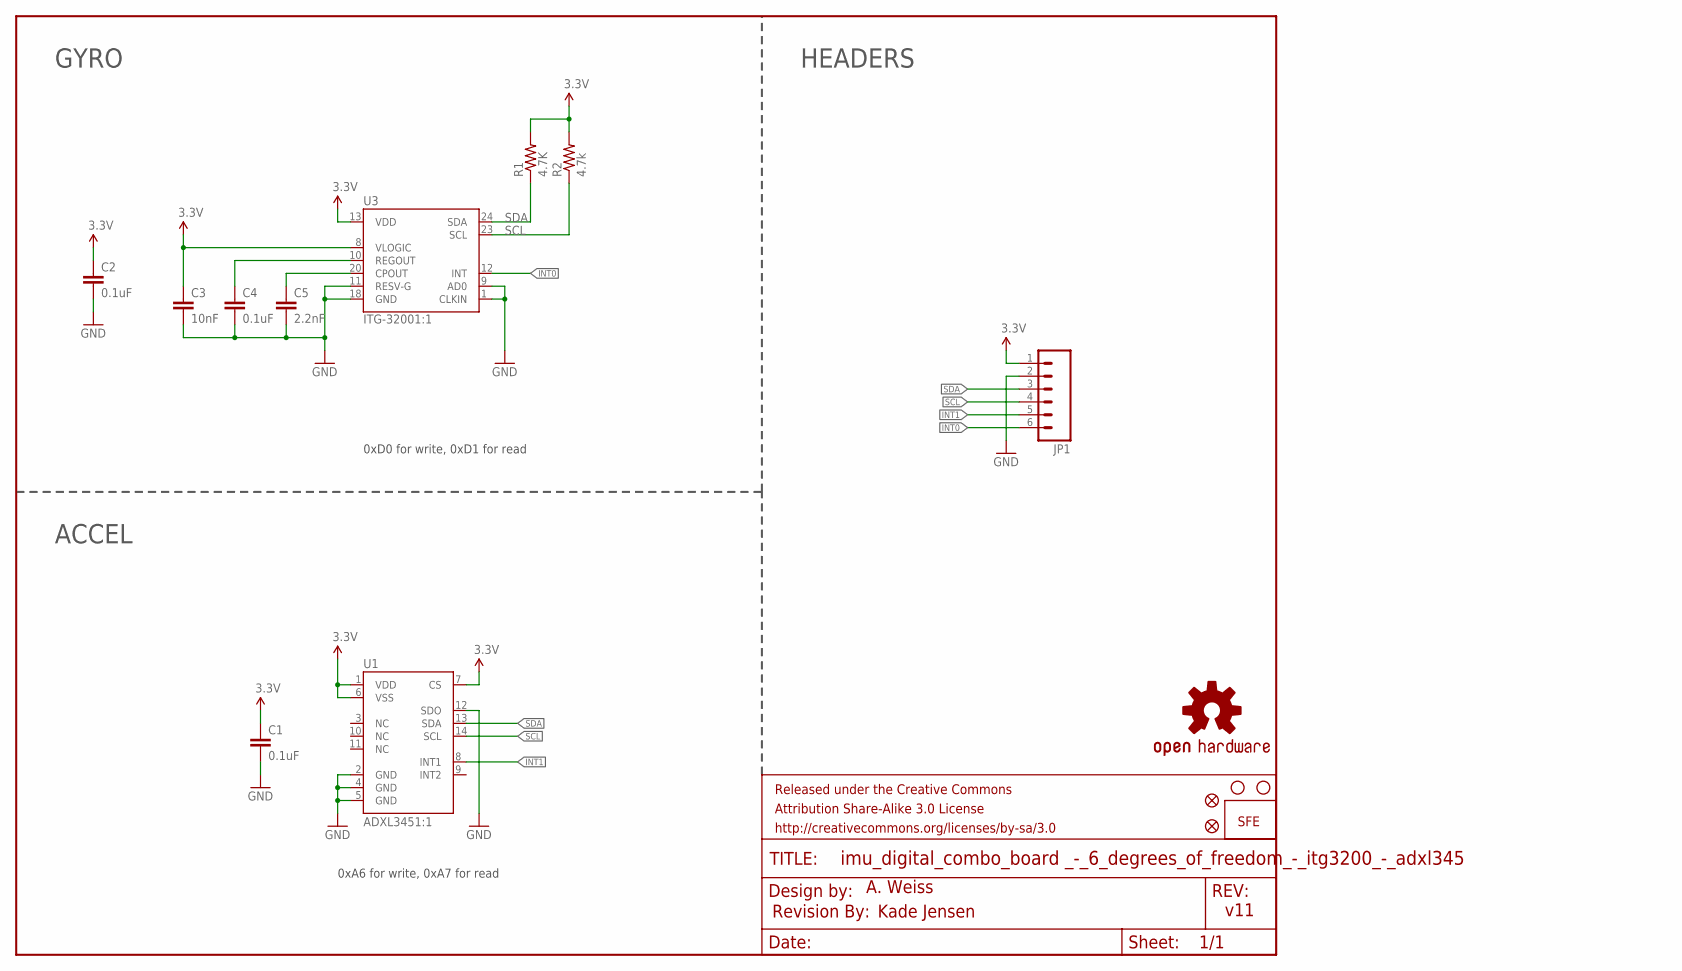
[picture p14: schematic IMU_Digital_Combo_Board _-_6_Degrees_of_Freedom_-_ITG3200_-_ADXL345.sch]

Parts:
C1, C2, C4: 0.1uF; 0603-CAP
C3: 10nF; 0603-CAP
C5: 2.2nF; 0603-CAP
FRAME1: FRAME-LETTER; CREATIVE_COMMONS
JP1: M06SIP; 1X06
JP2, JP5: STAND-OFF
JP3: LOGO-SFESK; SFE-LOGO-FLAME
JP4, JP6: FIDUCIAL1X2; FIDUCIAL-1X2
R1: 4.7K; 0603-RES
R2: 4.7k; 0603-RES
U1: ADXL3451:1; LGA14
U3: ITG-32001:1; QFN-24_ITG3200_1:1
U$1: REVISION
U$2: OSHW-LOGOS; OSHW-LOGO-S

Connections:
3.3V: C1.1, C2.1, C3.1, JP1.1, R1.2, R2.2, U1.1 (VDD), U1.6 (VSS), U1.7 (CS), U3.8 (VLOGIC), U3.13 (VDD)
GND: C1.2, C2.2, C3.2, C4.2, C5.2, JP1.2, U1.2 (GND), U1.4 (GND), U1.5 (GND), U1.12 (SDO), U3.1 (CLKIN), U3.9 (AD0), U3.11 (RESV-G), U3.18 (GND)
INT0: JP1.6, U3.12 (INT)
INT1: JP1.5, U1.8 (INT1)
unnamed: C5.1, U3.20 (CPOUT)
unnamed: C4.1, U3.10 (REGOUT)
SCL: JP1.4, R2.1, U1.14 (SCL), U3.23 (SCL)
SDA: JP1.3, R1.1, U1.13 (SDA), U3.24 (SDA)

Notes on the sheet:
A. Weiss
GYRO
ACCEL
HEADERS
0xD0 for write, 0xD1 for read
0xA6 for write, 0xA7 for read
Kade Jensen
v11

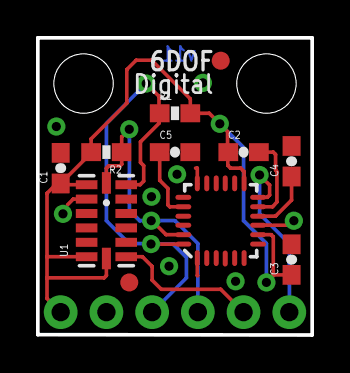
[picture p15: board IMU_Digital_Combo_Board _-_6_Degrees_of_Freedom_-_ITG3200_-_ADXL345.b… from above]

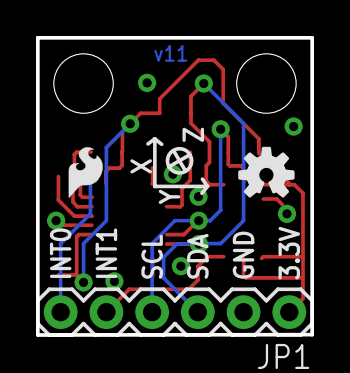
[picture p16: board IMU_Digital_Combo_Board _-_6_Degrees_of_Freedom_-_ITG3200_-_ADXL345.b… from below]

Board: 2 copper layers, 15.2 x 16.5 mm, 18 parts (3 on the bottom side), 8 nets.

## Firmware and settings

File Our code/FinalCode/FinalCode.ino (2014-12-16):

#include "EEPROM.h"
#include <Adafruit_GFX.h>    // Core graphics library
#include <Adafruit_ST7735.h> // Hardware-specific library
#include <SPI.h>


int upper_threshold, lower_threshold;





int in_ADC0, in_ADC1;  //variables for 2 ADCs values (ADC0, ADC1)
int pot0, pot1, pot2, out_DAC0, out_DAC1; //variables for 3 pots (ADC8, ADC9, ADC10)
int pot0_mod_old = 0, pot1_mod_old = 0, pot2_mod_old = 0;

const int LED         = 3;
const int FOOTSWITCH  = 7;
const int TOGGLE      = 2;
const int SAVE_BUTTON = 1;
const int TFT_CS      = 10;
const int TFT_RST     = 8;
const int TFT_DC      = 9;

const int STANDBY_MODE = 0;
const int BUTTON_MODE  = 1;
const int SENSOR_MODE  = 2;

const int DEBOUNCE_DELAY = 50;

const int MIN =     0;
const int MAX =  4096;

const int MIN_SCREEN =   0;
const int MAX_SCREEN = 115;

const int MIN_POT   =     0;
const int MAX_POT   =  4096;
const int LIMIT_POT = 10000;

const int MIN_SENSOR =   0;
const int MAX_SENSOR = 180;

Adafruit_ST7735 tft = Adafruit_ST7735(TFT_CS,  TFT_DC, TFT_RST);

int footswitch_detect;
int footswitch_detect_old;
int footswitch_detect_older;

int save_button_detect;
int save_button_press_time;
boolean save_button_pressed;

int footswitch_mode = STANDBY_MODE;

int last_debounce_time = 0;
int last_update_time   = 0;

int p0 = 0, p1 = 0, p2 = 0;
int p0_old, p1_old, p2_old;


byte incomingByte;
byte byteTemp;
int16_t counter;
int16_t currentInt;
int16_t int1;
byte byteArray[3];
byte byte1;
byte byte2;
byte byte3;
byte lastByte;
int16_t angles[3];
int16_t mask;



void setup()
{
  //ADC Configuration
  ADC->ADC_MR |= 0x80;   // DAC in free running mode.
  ADC->ADC_CR = 2;       // Starts ADC conversion.
  ADC->ADC_CHER = 0xFFFF; // Enable all ADC channels

  //DAC Configuration
  analogWrite(DAC0, 0); // Enables DAC0
  analogWrite(DAC1, 0); // Enables DAC0




  pinMode(FOOTSWITCH, INPUT);
  // pinMode(SAVE_BUTTON, INPUT);
  pinMode(LED, OUTPUT);

  tft.initR(INITR_BLACKTAB);

  tft.setRotation(-1);
  tft.setTextSize(2);
  tft.fillScreen(ST7735_WHITE);
  tft.setTextColor(ST7735_RED);
  tft.println("EFFECT NAME");
  tft.println("");
  tft.println("          P1");
  tft.println("");
  tft.println("          P2");
  tft.println("");
  tft.println("          P3");

  // record the state of the footswitch when turned on
  footswitch_detect_old = digitalRead(FOOTSWITCH);
  footswitch_detect_older = footswitch_detect_old;

  p0_old = p0;
  p1_old = p1;
  p2_old = p2;

  // initialize serial communication (for edge (on/off) detection)
  Serial.begin(9600);

  // initialize the XBee's serial port transmission
  Serial1.begin(57600);

  // From XBee
  lastByte = (byte)0;
}



void loop() {
  readFootSwitch();
  updateScreen();
  // readSaveButton();

  while ((ADC->ADC_ISR & 0x1CC0) != 0x1CC0); // wait for ADC 0,1,8,9,10 conversion complete.
  in_ADC0 = ADC->ADC_CDR[7];                 // read data from ADC0
  in_ADC1 = ADC->ADC_CDR[6];                 // read data from ADC1

  // POT0=ADC->ADC_CDR[10];                 // read data from ADC8
  // POT1=ADC->ADC_CDR[11];                 // read data from ADC9
  // POT2=ADC->ADC_CDR[12];                 // read data from ADC10

  switch (footswitch_mode) {
    case STANDBY_MODE:
      Serial.println("Standby Mode ");
      break;

    case BUTTON_MODE:
      Serial.println("Button Mode ");
      readPotentiometer();
      break;

    case SENSOR_MODE:
      Serial.println("Sensor Mode ");
      readSensor();
      break;

    default:
      Serial.print("Invalid state ");
  }
  
  upper_threshold=map(p0,0,4095,4095,2047);
  lower_threshold=map(p0,0,4095,0000,2047);
  
  if(in_ADC0>=upper_threshold) in_ADC0=upper_threshold;
  else if(in_ADC0<lower_threshold)  in_ADC0=lower_threshold;
 
  if(in_ADC1>=upper_threshold) in_ADC1=upper_threshold;
  else if(in_ADC1<lower_threshold)  in_ADC1=lower_threshold;
 
  //adjust the volume with POT2
  out_DAC0=map(in_ADC0,0,4095,1,p2);
  out_DAC1=map(in_ADC1,0,4095,1,p2);
 
  //Write the DACs
  dacc_set_channel_selection(DACC_INTERFACE, 0);          //select DAC channel 0
  dacc_write_conversion_data(DACC_INTERFACE, out_DAC0);   //write on DAC
  dacc_set_channel_selection(DACC_INTERFACE, 1);          //select DAC channel 1
  dacc_write_conversion_data(DACC_INTERFACE, out_DAC1);   //write on DAC

}



void testdrawtext(char *text, uint16_t color) {
  tft.setCursor(0, 0);
  tft.setTextColor(color);
  tft.setTextWrap(true);
  tft.print(text);
}

void readFootSwitch() {
  footswitch_detect = digitalRead(FOOTSWITCH);

  if (footswitch_detect != footswitch_detect_old) {
    last_debounce_time = millis();
  }

  if (footswitch_detect != footswitch_detect_older && millis() - last_debounce_time > DEBOUNCE_DELAY) {
    footswitch_mode = (footswitch_mode + 1) % 3;
    footswitch_detect_older = footswitch_detect;
  }

  footswitch_detect_old = footswitch_detect;
}


void readSaveButton() {
  save_button_detect = digitalRead(SAVE_BUTTON);

  if (save_button_detect == HIGH) {
    last_debounce_time = millis();

    if (save_button_pressed = true) {
      if (millis() - save_button_press_time > 3000) {
        EEPROM.write(0, p0);
        EEPROM.write(1, p1);
        EEPROM.write(2, p2);
      } else {
        p0 = EEPROM.read(0);
        p1 = EEPROM.read(1);
        p2 = EEPROM.read(2);
      }

      save_button_pressed = false;
    }
  }

  if (save_button_detect == LOW && millis() - last_debounce_time > DEBOUNCE_DELAY && save_button_pressed == false) {
    save_button_press_time = millis();
    save_button_pressed = true;
  }
}

void readPotentiometer() {
  int pot0_mod = ADC->ADC_CDR[2]; //read from pot0
  pot0 = updatePot(pot0, pot0_mod_old, pot0_mod);
  pot0_mod_old = pot0_mod;

  int pot1_mod = ADC->ADC_CDR[1]; //read from pot1
  pot1 = updatePot(pot1, pot1_mod_old, pot1_mod);
  pot1_mod_old = pot1_mod;

  int pot2_mod = ADC->ADC_CDR[0]; //read from pot2
  pot2 = updatePot(pot2, pot2_mod_old, pot2_mod);
  pot2_mod_old = pot2_mod;

  p0 = map(pot0, MIN_POT, LIMIT_POT, MIN, MAX);
  p1 = map(pot1, MIN_POT, LIMIT_POT, MIN, MAX);
  p2 = map(pot2, MIN_POT, LIMIT_POT, MIN, MAX);
}


int updatePot(int pot, int pot_mod_old, int pot_mod) {
  int value = 0;
  if ((pot_mod - pot_mod_old) < -0.9 * MAX_POT) {
    value = MAX_POT + pot_mod - pot_mod_old;//+POTSENSOR

    if ((pot + value) > LIMIT_POT) {
      pot = LIMIT_POT;
    }
    else {
      pot = pot + value ;
    }
  }
  else if ((pot_mod - pot_mod_old) > 0.9 * MAX_POT) {
    value = - MAX_POT + pot_mod - pot_mod_old;//+POTSENSOR
    if ((pot + value) < MIN_POT) {
      pot = MIN_POT;
    }
    else {
      pot = pot + value ;
    }
  }
  else if ((pot_mod - pot_mod_old) > 0) {
    value = pot_mod - pot_mod_old;//+POTSENSOR
    if ((pot + value) > LIMIT_POT) {
      pot = LIMIT_POT;
    }
    else {
      pot = pot + value ;
    }
  }
  else if ((pot_mod - pot_mod_old) < 0) {
    value = pot_mod - pot_mod_old;//+POTSENSOR
    if ((pot + value) < MIN_POT) {
      pot = MIN_POT;
    }
    else {
      pot = pot + value ;
    }
  }
  return pot;
}


void updateScreen() {
  if (millis() - last_update_time > 100) {
    last_update_time = millis();

    if (p0_old < p0) {
      tft.fillRoundRect(MIN_SCREEN, 32, map(p0, MIN, MAX, MIN_SCREEN, MAX_SCREEN), 16, 0, ST7735_BLUE);
    }
    if (p0_old > p0) {
      tft.fillRoundRect(map(p0, MIN, MAX, MIN_SCREEN, MAX_SCREEN), 32, map(p0, MIN, MAX, MAX_SCREEN, MIN_SCREEN), 16, 0, ST7735_WHITE);
    }

    p0_old = p0;


    if (p1_old < p1) {
      tft.fillRoundRect(MIN_SCREEN, 64, map(p1, MIN, MAX, MIN_SCREEN, MAX_SCREEN), 16, 0, ST7735_BLUE);
    }
    if (p1_old > p1) {
      tft.fillRoundRect(map(p1, MIN, MAX, MIN_SCREEN, MAX_SCREEN), 64, map(p1, MIN, MAX, MAX_SCREEN, MIN_SCREEN), 16, 0, ST7735_WHITE);
    }

    p1_old = p1;

    if (p2_old < p2) {
      tft.fillRoundRect(MIN_SCREEN, 96, map(p2, MIN, MAX, MIN_SCREEN, MAX_SCREEN), 16, 0, ST7735_BLUE);
    }
    if (p2_old > p2) {
      tft.fillRoundRect(map(p2, MIN, MAX, MIN_SCREEN, MAX_SCREEN), 96, map(p2, MIN, MAX, MAX_SCREEN, MIN_SCREEN), 16, 0, ST7735_WHITE);
    }

    p2_old = p2;
  }
}


void readSensor() {
  if (Serial1.available()) {

    // The general idea is that when the pedal ends its effect loop, there can be a very big buffer of bytes waiting, that are not good, so we clear it
    boolean header = false;
    lastByte = Serial1.read();

    while (Serial1.available() && !header) {
      incomingByte = Serial1.read();

      int1 = assembleInt(lastByte, incomingByte);

      //Serial.println("waiting"); // Uncomment this line to see how much it takes to clear the buffer

      if (int1 == -21846) {
        header = true;
      } else {
        lastByte = incomingByte;
      }
    }


    readAngles();
    lastByte = (byte)0;
  }
}

// assemble an int from the two bytes just read into byteArray
int16_t assembleInt(byte byte1, byte byte2) {

  currentInt = (int16_t)byte1 << 8;
  mask = 0xFF;
  mask = mask & (int16_t)byte2; // mask the first 8 bit to zero, in case the byte is sign-extended

  currentInt = currentInt | mask;

  // the byte1*256 + byte2 before is wrong because byte2 had been sign-extended - have to mask the first 8 bits
  //mask = 0xFF;
  //currentInt = byte1*256 + (byte2 & mask);
  return currentInt;
}


void readAngles() {
  for (int i = 0; i < 3; i++) {
    while (!Serial1.available()) {

      Serial.println("----Im waiting111111-");
    }

    byteArray[0] = Serial1.read();


    while (!Serial1.available()) {

      Serial.println("----Im waiting222222-");
    }

    byteArray[1] = Serial1.read();
    angles[i] = assembleInt(byteArray[0], byteArray[1]);
  }

  if (angles[0] >= 0 && angles[0] <= 360 && angles[1] >= 0 && angles[1] <= 360 && angles[2] >= 0 && angles[2] <= 360) {
    Serial.print(angles[0]);
    Serial.print("|");
    Serial.print(angles[1], DEC);
    Serial.print("|");
    Serial.print(angles[2], DEC);
    Serial.print("|");

    Serial.println("");

    // Writing the angles into the global variables
    p0 = map(angles[0], MIN_SENSOR, MAX_SENSOR, MIN, MAX);
    p1 = map(angles[1], MIN_SENSOR, MAX_SENSOR, MIN, MAX);
    p2 = map(angles[2], MIN_SENSOR, MAX_SENSOR, MIN, MAX);
  }
}

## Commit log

2014-10-14 Cahier des charges
2014-10-14 Adjouté les photos de la séance de soudre
2014-10-14 changement des dossiers
2014-10-14 Andi's nouvelle code de 3Mode
    avec les Switch statements
2014-10-14 Andi's nouvelle code de 3Mode
    avec des Switch statements
2014-11-04 Downloaded data sheet for the IMY
    [IMU_Digital_Combo_Board _-_6_Degrees_of_Freedom_-_ITG3200_-_ADXL345.brd, IMU_Digital_Combo_Board _-_6_Degrees_of_Freedom_-_ITG3200_-_ADXL345.sch]
2014-11-04 changelent de code
2014-11-11 sensor software
2014-11-11 Final loop for 1 Button
    we'll have to modify the program with 2 other buttons, and the sensors
2014-11-11 bug on final 1
    now it works!
    [continuousButtonsFinal1.ino]
2014-11-25 ADXL345 adapted library for DUE
    [IMU_Digital_Combo_Board _-_6_Degrees_of_Freedom_-_ITG3200_-_ADXL345.brd, IMU_Digital_Combo_Board _-_6_Degrees_of_Freedom_-_ITG3200_-_ADXL345.sch]
2014-11-25 IMU sensor library and cube visualization tool
    These three folders allow us to visualize the data collected by the
    IMU. It uses the library and the code from
    http://bildr.org/2012/03/stable-orientation-digital-imu-6dof-arduino/ -
    very grateful for the library. The code has been adapted to run on
    Arduino DUE (instead of UNO for which the code and library are written
    for).
    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
2014-12-02 MasterCode - just began
    Integrated the code for the sensor with the threeModesDebounce
2014-12-11 Testing and fixing code
    [test_XBee_Siyu.ino, test_XBee_SiyuV4.ino]
2014-12-15 Code is tested. Distortion in the final code not working yet.
    [FinalCode.ino, NotTested.ino]
2014-12-15 Commenting the code for the sensor
2014-12-16 Changing the Yaw angle
2014-12-16 Update distortionSensorsV2.ino
    Commented code for button mode
2015-03-31 deleting directorys
    [IMU_Digital_Combo_Board _-_6_Degrees_of_Freedom_-_ITG3200_-_ADXL345.brd, IMU_Digital_Combo_Board _-_6_Degrees_of_Freedom_-_ITG3200_-_ADXL345.sch]
2015-03-31 J'ajoute les cartes du shield recepteur
    [ShieldRecepteur.fzz]
2015-03-31 shield principal
    [Capteur PCB.fzz, Pedale Schema 3103.fzz, Pedale Schema 3103_2.fzz]

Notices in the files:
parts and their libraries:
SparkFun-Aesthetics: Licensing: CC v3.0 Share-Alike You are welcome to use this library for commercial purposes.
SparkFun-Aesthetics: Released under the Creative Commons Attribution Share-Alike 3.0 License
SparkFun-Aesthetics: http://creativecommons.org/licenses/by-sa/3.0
